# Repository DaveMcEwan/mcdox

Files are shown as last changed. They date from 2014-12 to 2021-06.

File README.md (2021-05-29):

mcdox - Mechanical Computer Keyboard
====================================

Layout is similar to than of the Ergodox project, but in a unibody case.

Subdirectories
--------------

- case - Lasercut design produced by exporting SVGs from KiCAD.
- doc - Documents like datasheets stored for handy reference.
- keycap - STL model generator written in OpenSCAD suitable for FDM printing.
  Generated models are tracked in `keycap/stl` because it takes a while (~10
  minutes) to generate them.
- pcb/ctrl - TODO Breakout PCB for connecting controller to switch grids.
- pcb/hand - Reversible PCB which connects the switches in a grid.
  - 38 buttons distributed over 5 rows, 8 columns.
  - Lengths beside mounting holes (6mm, 15mm, 25mm) are for standoffs to
    achieve a tenting.
  - Connect to control board with 15 core, 1mm pitch FFC-FPC cable.
    <https://www.te.com/usa-en/product-1-84953-5.html>
    <https://www.digikey.com/en/products/detail/te-connectivity-amp-connectors/1-84953-5/2567541>
    <https://uk.farnell.com/amp-te-connectivity/1-84953-5/connector-ffc-fpc-15pos-1rows/dp/3398659>
    <https://uk.farnell.com/multicomp-pro/mp-ffca10150503a/ffc-cord-15p-same-side-50mm-wht/dp/3385337>
    <https://uk.farnell.com/multicomp-pro/mp-ffca10151003a/ffc-cord-15p-same-side-100mm-wht/dp/3385339>
  - Low level lighting with LED on top and/or bottom, depending how the case
    looks.
  - All diodes (1N4148 compatible), LEDs, and resistors are 0603 (imperial).
- release - Stuff that's actually been manufactured.

BOM
---

- Keycaps - The functionally simplest parts which are also the most difficult to
  source.
  18x 1.5u, 56x 1u
- Case - Standard 3mm acrylic from laser cutter.
- PCBs - 1.2mm FR4, 2-layer, 0.15mm width/clearance
  2x mcdoxHand, 1x mcdoxCtrl
- Switches - CherryMX, or compatible like Gateron, Kailh.
  74x
- Diodes - 1 per switch.
  74x
- Microcontroller - Arduino Pro Micro from Sparkfun, or clone.
- FPC connectors
  4x
- FPC cables - Connect hand PCBs to central controller.
- LEDs - 0603 footprint
  2x
- Resistors - For LEDs and switch matrix.
  10x 220R 0603
- Pushbutton - For putting Arduino Pro Micro into programming mode.
  1x

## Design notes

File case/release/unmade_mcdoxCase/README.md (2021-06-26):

Currently unmade - Ready for any future remakes.

Adjustments after session at MVB hackspace on 2020-12-03.
1. Asymmetric hole mistake stops layers being reversible.
  It was off by 5mm but still snapped to grid.
2. Recess for ArduinoProMirco widened by 1mm as it was a very tight press fit.
  This also fixed the very slight asymmetry of the top outline which wasn't
  snapped to grid.
3. Switch hole paths made with straight segments and simplified paths.
  Hope to avoid the odd path planning seen with segments cut in seemingly random
  order.
  It was still the correct cut-points but wasted time flying the lens rather
  than cutting.
4. Pinhole for programming pushbutton through bottom cover.
5. Slightly enlargened keycap cutouts in innerTop to stop caps getting jammed.

DXFs derived from case.svg
--------------------------
```
For each cut layer of case.svg:
  Save a copy as DXF14 using named layer.
  Open DXF in Inkscape.
  Select all, set color to red.
  Reposition for paper size of 400x200mm.
```

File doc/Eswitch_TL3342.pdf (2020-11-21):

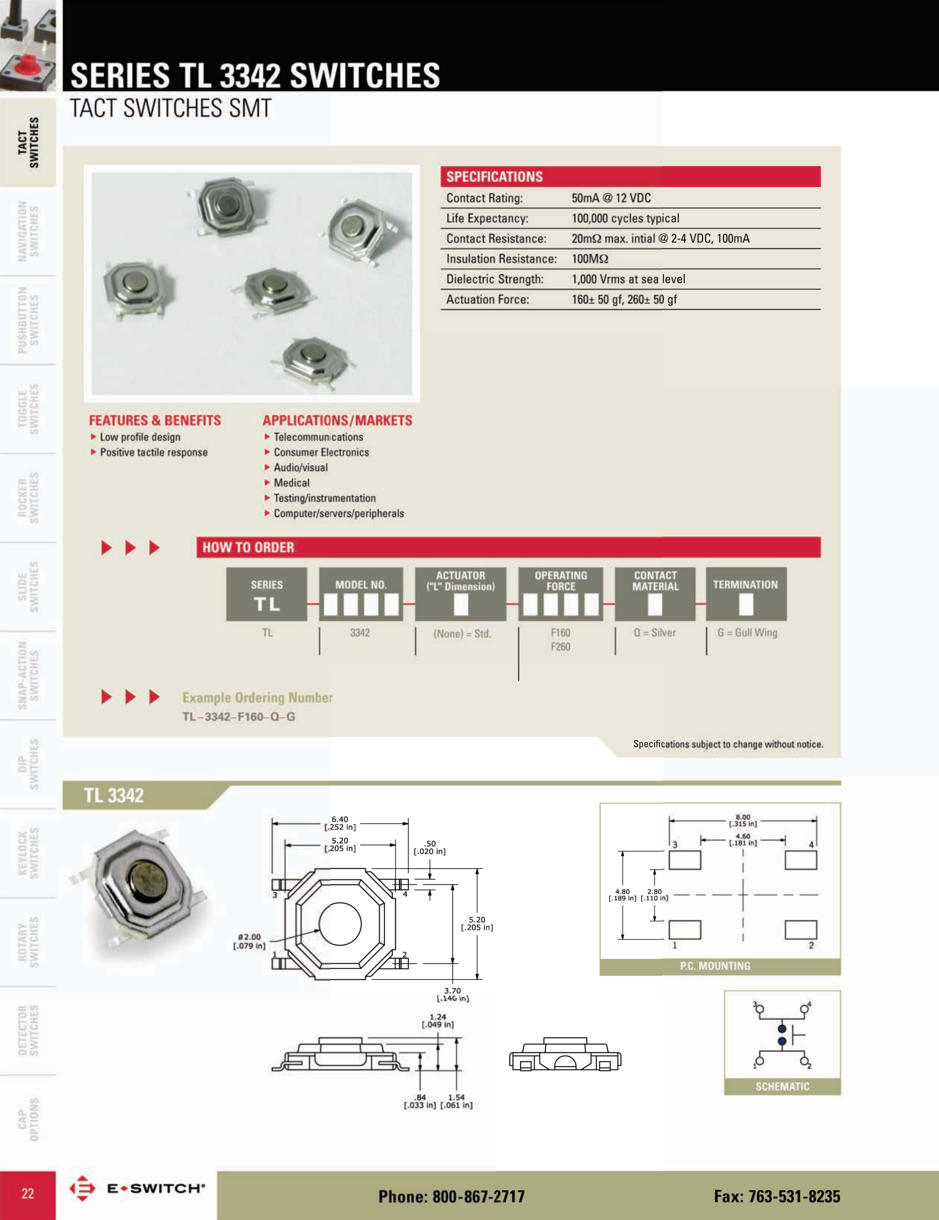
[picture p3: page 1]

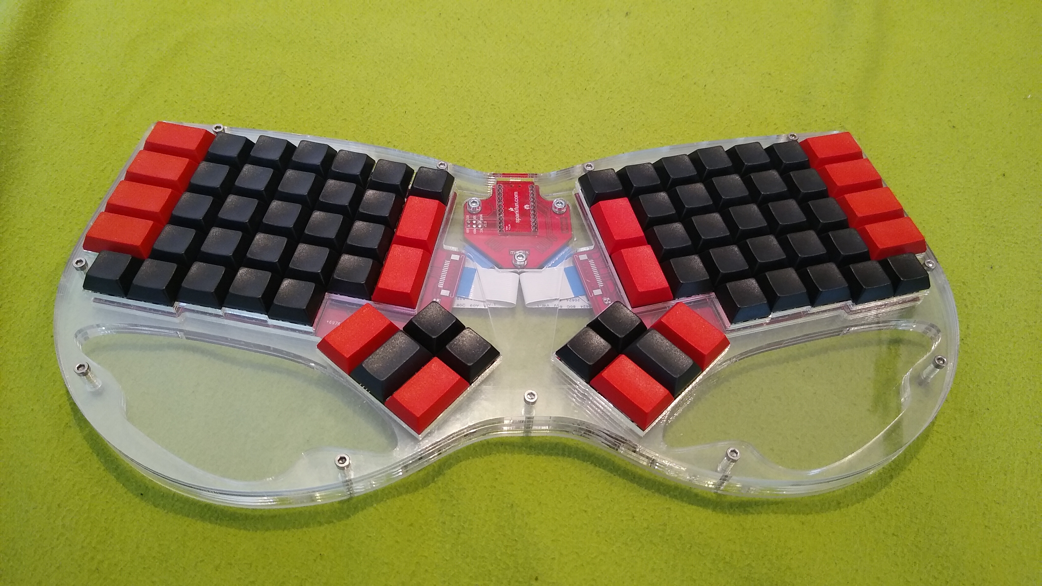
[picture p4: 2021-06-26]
release/mcdoxNov2020/img/top0.jpg

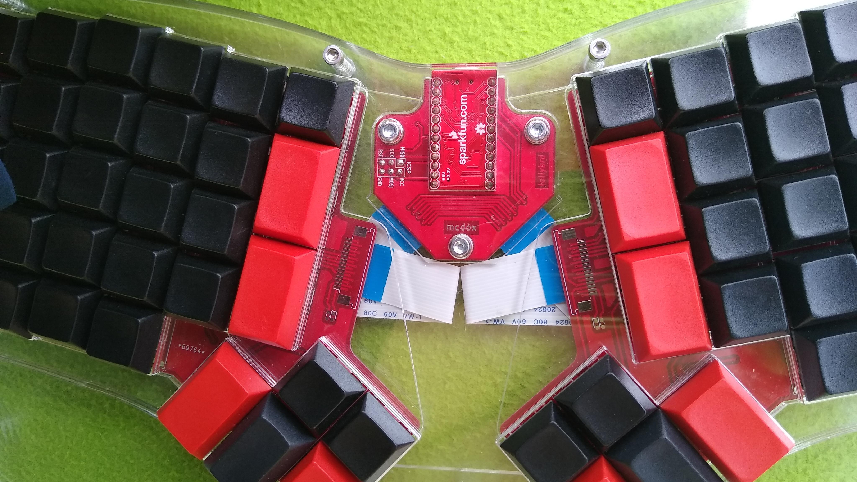
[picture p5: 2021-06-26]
release/mcdoxNov2020/img/ctrl1.jpg

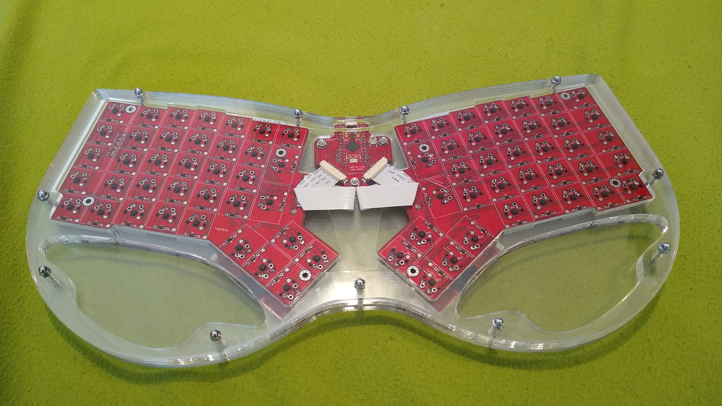
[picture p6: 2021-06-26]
release/mcdoxNov2020/img/bottom0.jpg

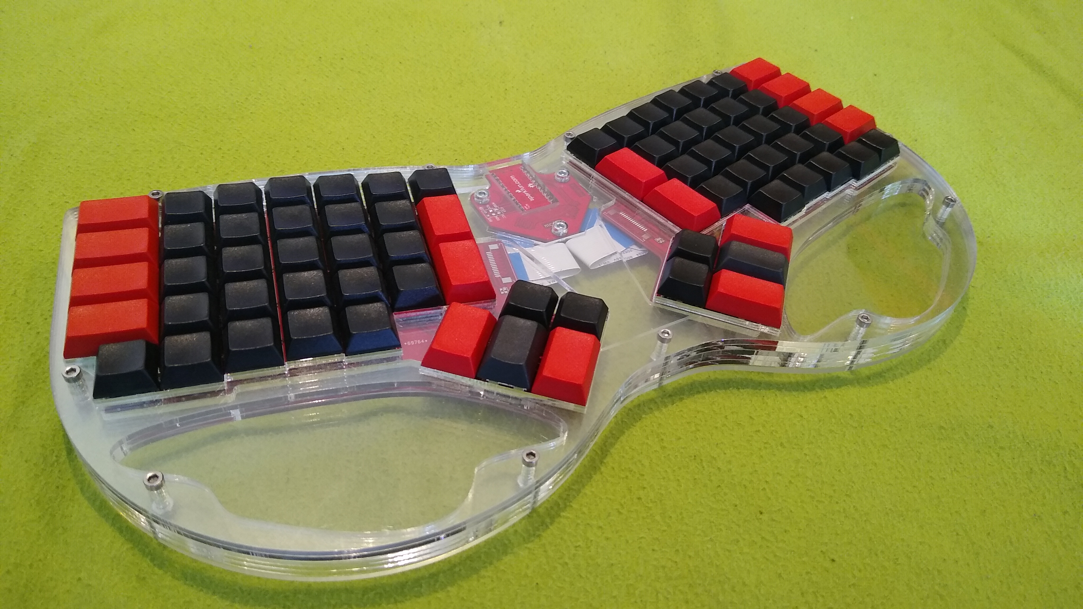
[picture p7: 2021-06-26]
release/mcdoxNov2020/img/top1.jpg

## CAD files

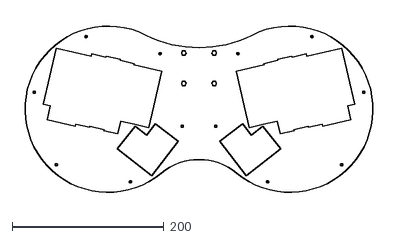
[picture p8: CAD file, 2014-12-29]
case/dxf/mcdox_top0_4mm.dxf
481.3 x 241.5

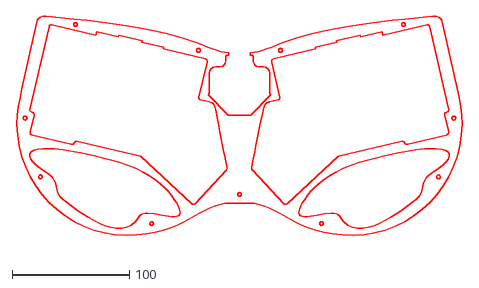
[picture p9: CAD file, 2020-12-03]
case/release/2020-12-03_MVB1.06_mcdoxCase/cut.innerBottom1.dxf
381.5 x 197.5

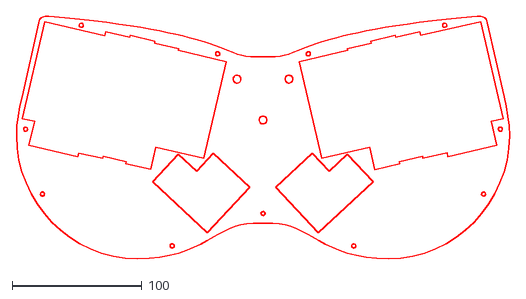
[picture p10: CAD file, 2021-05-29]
case/release/unmade_mcdoxCase/cut.innerTop.dxf
380.0 x 186.8

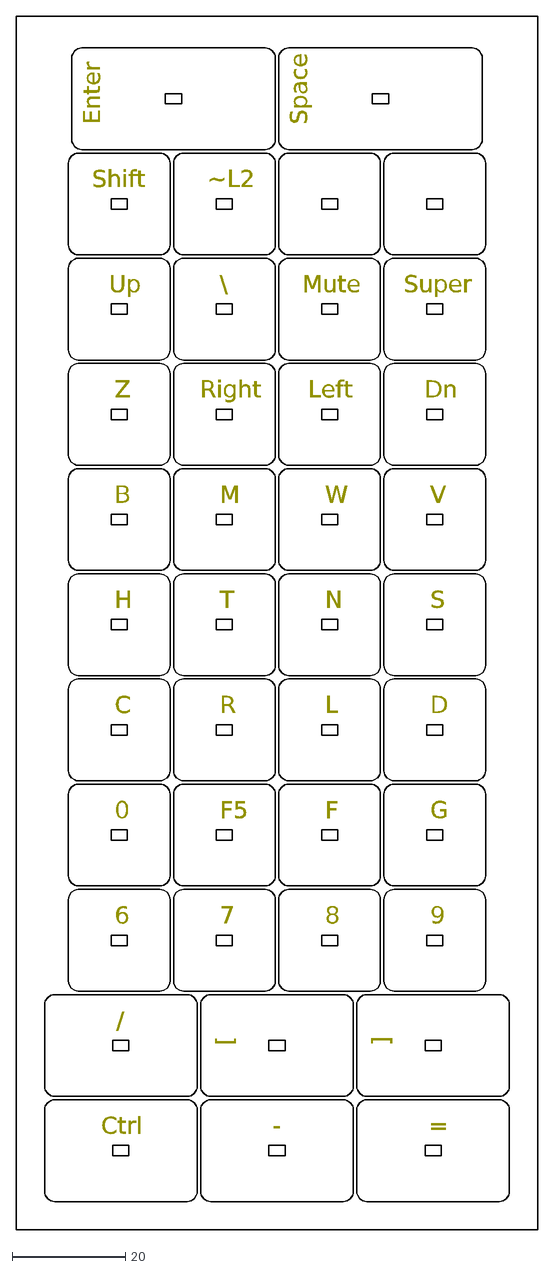
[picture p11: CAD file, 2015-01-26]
keycap/dxf/alps_caps_mcdoxright_3mm.dxf
Ctrl
-
=
/
[
]
6
7
8
9
0
F5
F
G
C
R
L
D
H
T
N
S
B
M
W
V
Z
Right
Left
Dn
Up
\
Mute
Super
Shift
~L2
Enter
Space

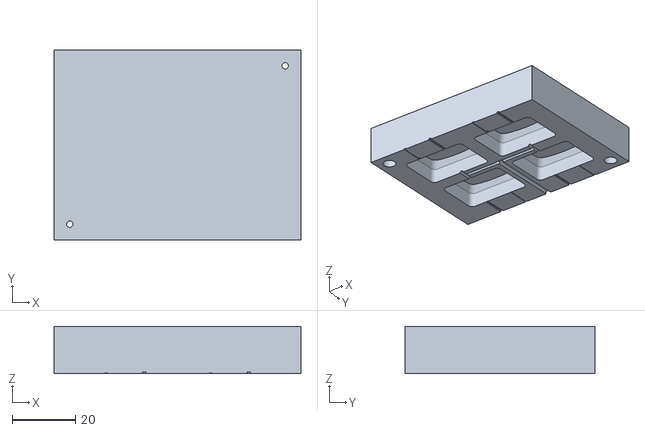
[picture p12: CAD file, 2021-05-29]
keycap/stl/moldUpper,keycap,DSA,CherryMX,1.5u,noBump.stl
78.0 x 60.0 x 15.0

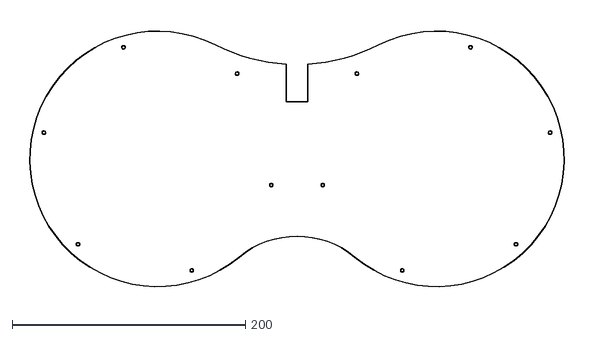
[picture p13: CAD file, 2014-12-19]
case/dxf/mcdox_base0_2mm.dxf
481.3 x 241.5

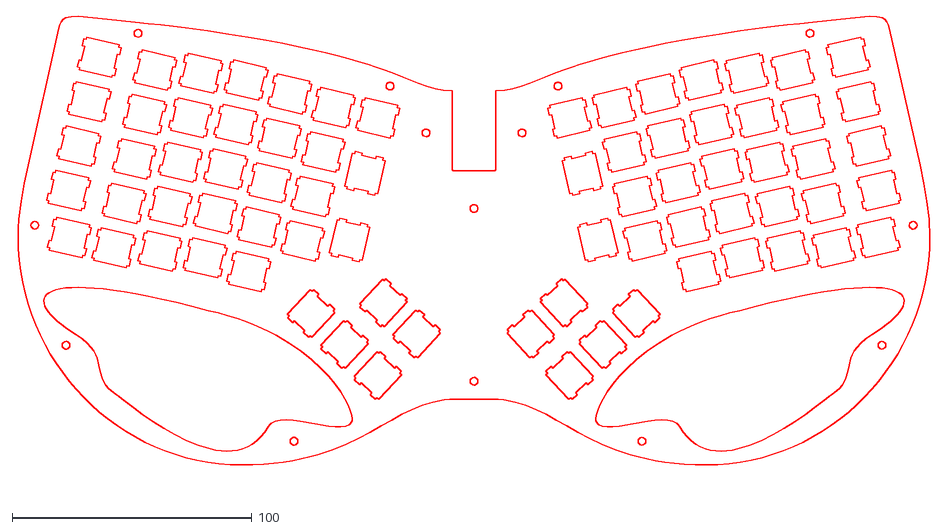
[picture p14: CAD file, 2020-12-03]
case/release/2020-12-03_MVB1.06_mcdoxCase/cut.mount.dxf
381.5 x 197.5

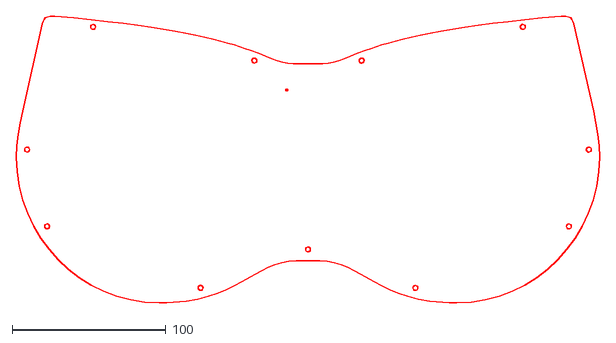
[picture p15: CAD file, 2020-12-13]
case/release/unmade_mcdoxCase/cut.coverBottom.dxf
380.0 x 186.8

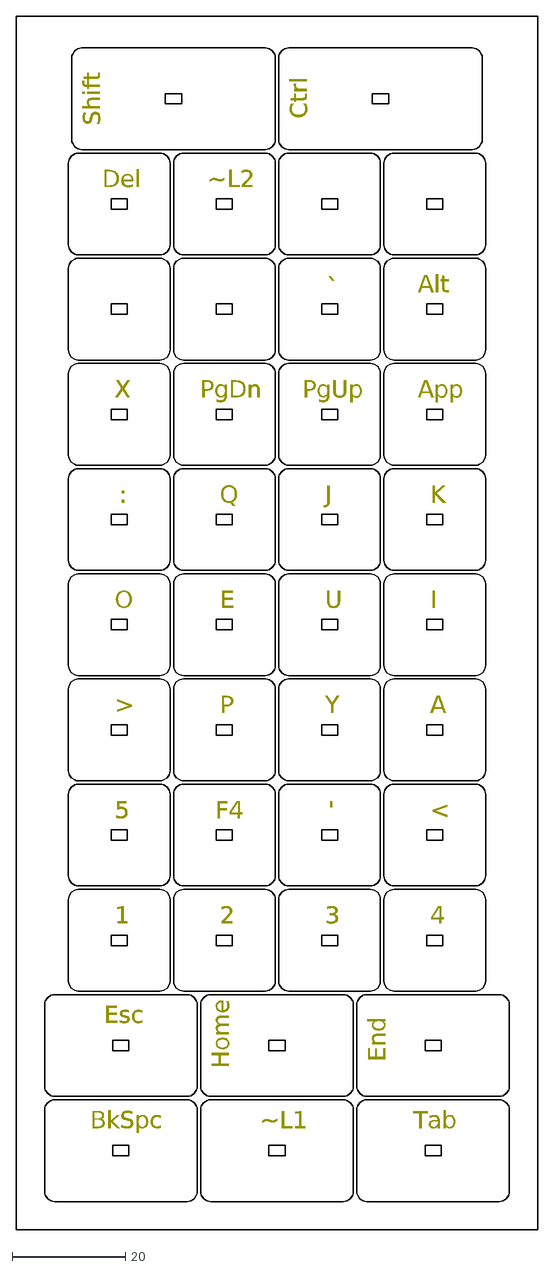
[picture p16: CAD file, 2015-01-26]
keycap/dxf/alps_caps_mcdoxleft_3mm.dxf
BkSpc
~L1
Tab
Esc
Home
End
1
2
3
4
5
F4
'
<
>
P
Y
A
O
E
U
I
:
Q
J
K
X
PgDn
PgUp
App
`
Alt
Del
~L2
Shift
Ctrl

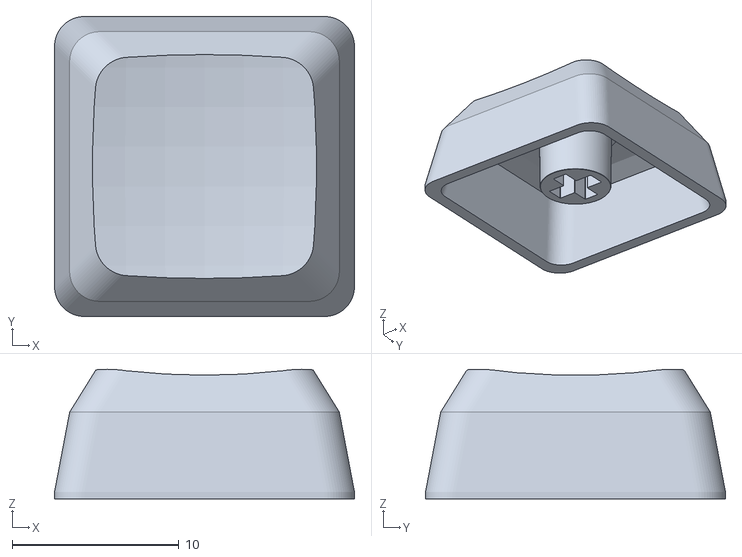
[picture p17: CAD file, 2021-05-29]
keycap/stl/keycap,DSA,CherryMX,1u,noBump.stl
18.0 x 18.0 x 7.77

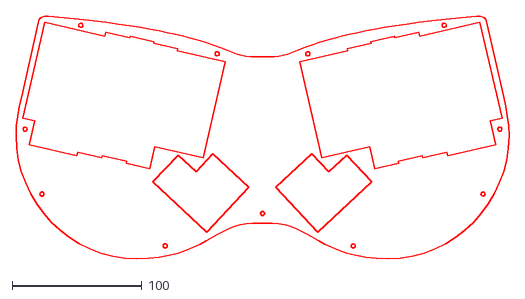
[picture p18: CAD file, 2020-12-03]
case/release/2020-12-03_MVB1.06_mcdoxCase/cut.coverTop.dxf
380.0 x 186.9

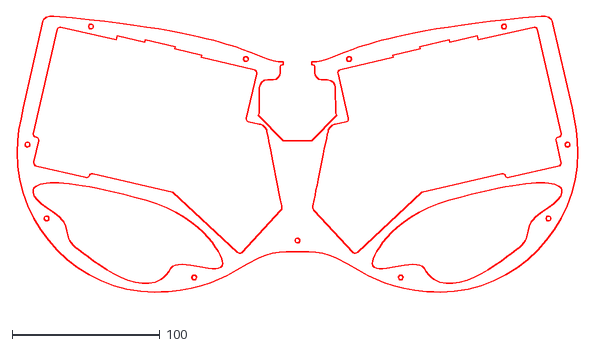
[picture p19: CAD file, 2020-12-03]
case/release/unmade_mcdoxCase/cut.innerBottom1.dxf
381.5 x 197.5

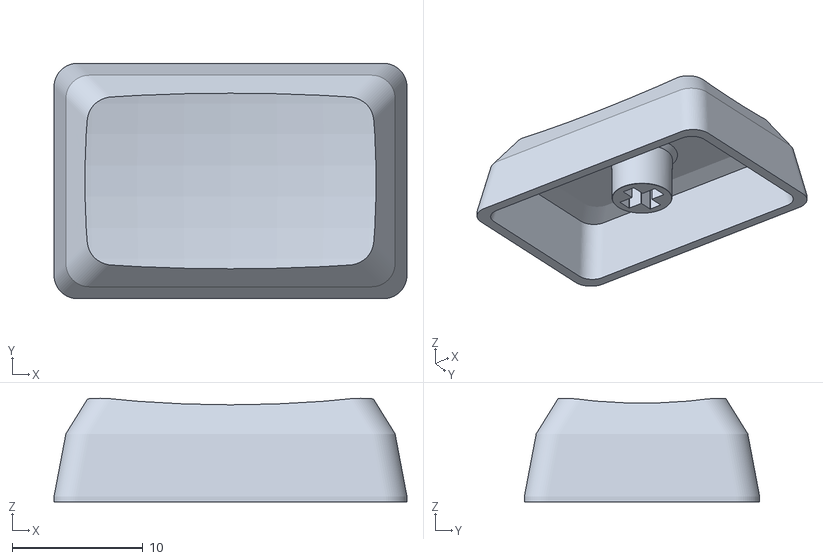
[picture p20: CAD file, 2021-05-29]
keycap/stl/keycap,DSA,CherryMX,1.5u,noBump.stl
27.0 x 18.0 x 7.92

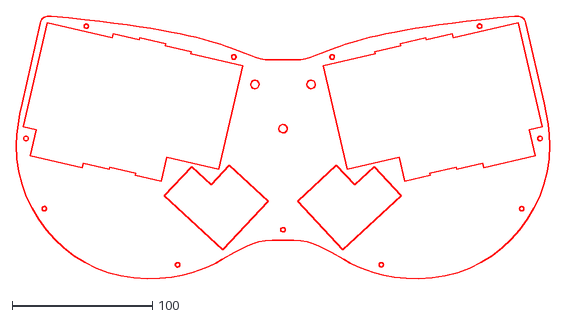
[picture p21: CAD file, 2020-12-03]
case/release/2020-12-03_MVB1.06_mcdoxCase/cut.innerTop.dxf
380.0 x 186.9

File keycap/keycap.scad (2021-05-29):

use <keycapStem.scad>
use <keycapShell.scad>

// Overrideable parameters.
stemNum     = 1;    // Stem shape (CherryMX:1, Matias/ALPS:2)
shellNum    = 1;    // Profile (DSA:1, DCS:2)
uMul        = 1.5;  // Length multiple. Ergodox has (1, 1.5, 2)
doBump      = 0;    // Enable homing bump.

baseUnit = 18.0;

/** Full keycap

mold 0 -> no mold
     1 -> lower negative
     2 -> lower positive, Only for registration trough.
     3 -> upper positive
 */
module keycap (stemNum=1, shellNum=1, uMul=1.0, doBump=0, mold=0) {
  /*
  echo("keycap.scad keycap()");
  echo("\t stemNum=", stemNum);
  echo("\t shellNum=", shellNum);
  echo("\t uMul=", uMul);
  echo("\t doBump=", doBump);
  echo("\t mold=", mold);
  */

  if (1 == mold) {

    difference() {
      color("crimson")
      if (2 == shellNum) innerDCS(u=uMul);
      else               innerDSA(u=uMul);

      color("lightblue")
      if (2 == stemNum) stemMatiasALPS();
      else              stemCherryMX();
    }

  } else if (2 == mold) {

      color("lightgreen")
      if (2 == shellNum) shellDCS(u=uMul, doBump=0);
      else               shellDSA(u=uMul, doBump=0);

  } else if (3 == mold) {

      color("lightgreen")
      if (2 == shellNum) outerDCS(uMul, doBump);
      else               outerDSA(uMul, doBump);

  } else {

    union() {
      color("lightgreen")
      if (2 == shellNum) shellDCS(uMul, doBump);
      else               shellDSA(uMul, doBump);

      color("lightblue")
      if (2 == stemNum) stemMatiasALPS();
      else              stemCherryMX();
    }

  }

}

keycap(stemNum, shellNum, uMul, doBump);

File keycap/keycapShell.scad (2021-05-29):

minDim = 0.001;

baseUnit = 18.0;
draft_deg = 20; // Large taper for easier mold removal, Set for anything.
registration_z = 0.4;

/** Rounded rectangle
*/
module roundedRect (width, height, radius) {
  x = width/2-radius;
  y = height/2-radius;
  hull() {
    translate([-x, -y, 0]) circle(r=radius, $fn=64);
    translate([-x,  y, 0]) circle(r=radius, $fn=64);
    translate([ x, -y, 0]) circle(r=radius, $fn=64);
    translate([ x,  y, 0]) circle(r=radius, $fn=64);
  }
}


module outerDSA (u=1.0, doBump=0) {
  // Top is smaller than base.
  xDiff = 5.3;
  yDiff = 5.3;

  topZ = 7.8;
  dishDepth = 1.2; // Bottom of dish is topZ-dishDepth above origin.
  corner_r = 1.8;

  /** dishVoidDSA Spherical cutout from the top face.
  */
  module dishVoidDSA (u=1.0) {
    r = 38;

    rotate([90, 0, 0])
    translate([0, r, 0])
    scale([u, 1, 1])
    sphere(r=r, $fn=100);
  }

  // Walls are almost straight, but edge at keycap midheight is slightly smaller
  // to make walls slant inwards (draft) for easier mold release.
  wallZ = 5.0;
  d = wallZ * tan(draft_deg); // Reduction length for draft angle.

  union() {
    difference() {
      hull() {
        linear_extrude(minDim)
        roundedRect(baseUnit*u, baseUnit, corner_r);

        translate([0, 0, wallZ])
        linear_extrude(minDim)
        roundedRect(baseUnit*u-d, baseUnit-d, corner_r);

        translate([0, 0, topZ])
        linear_extrude(minDim)
        roundedRect(baseUnit*u-xDiff, baseUnit-yDiff, corner_r);

        // Registration cutout in bottom mold half.
        translate([0, 0, -registration_z/2])
        linear_extrude(registration_z+minDim)
        roundedRect(baseUnit*u, baseUnit, corner_r);
      }

      translate([0, 0, topZ - dishDepth])
      dishVoidDSA(u);
    }

    // Homing bump
    // Usually on the two index finger keys (F,J on qwerty, U,H on dvorak).
    // Sometimes on DSA just a deeper dish is used.
    if (0 != doBump)
      translate([0, 0, topZ - 1.5*dishDepth])
      cylinder(h=0.9, r1=1.9, r2=0.7, center=false, $fn=32);
  }
}

module innerDSA (u=1.0) {
  wallT = 1.0; // Wall thickness
  roofT = 1.1;

  // Top is smaller than base.
  xDiff = 5.3;
  yDiff = 5.3;
  topZ = 6.6 - roofT; // outerDSA.topZ - dishDepth - roofT = 5.5

  corner_r = 1.5;

  // Walls are almost straight, but edge at keycap midheight is slightly smaller
  // to make walls slant inwards (draft) for easier mold release.
  wallZ = 5.0;
  d = wallZ * tan(draft_deg); // Reduction length for draft angle.

  hull() {
    translate([0, 0, -minDim])
    linear_extrude(minDim)
    roundedRect(baseUnit*u - 2*wallT, baseUnit - 2*wallT, corner_r);

    translate([0, 0, wallZ])
    linear_extrude(minDim)
    roundedRect(baseUnit*u-d - 2*wallT, baseUnit-d - 2*wallT, corner_r);

    translate([0, 0, topZ])
    linear_extrude(minDim)
    roundedRect(baseUnit*u-xDiff - 2*wallT, baseUnit-yDiff - 2*wallT, corner_r);

    // Registration cutout in bottom mold half.
    translate([0, 0, -minDim-registration_z])
    linear_extrude(registration_z+minDim)
    roundedRect(baseUnit*u - 2*wallT, baseUnit - 2*wallT, corner_r);
  }
}

module shellDSA (u=1.0, doBump=0) {
  difference() {
    outerDSA(u, doBump);

    innerDSA(u);
  }
}

translate([20, 0, 0])
shellDSA(1.0, 1);

translate([20, 30, 0])
shellDSA(1.5, 1);

translate([50, 0, 0])
color("lightblue")
outerDSA(1.0);

translate([50, 30, 0])
color("lightblue")
outerDSA(1.5);

translate([80, 0, 0])
color("red")
innerDSA(1.0);

translate([80, 30, 0])
color("red")
innerDSA(1.5);


module outerDCS (u=1.0, doBump=0) {
  // Top is smaller than base.
  xDiff = 6;
  yDiff = 4;

  topZ = 8.2;
  dishDepth = 1.0; // Bottom of dish is topZ-dishDepth above origin.
  corner_r = 1.8;

  /** dishVoidDCS Cylindrical cutout from the top face.
  */
  module dishVoidDCS (u=1.0) {
    r = 20;
    tilt_deg = 2.0;

    // Tilt direction is unclear for non-square, so lie cutout flat.
    if (1.0 == u)
      rotate([90-tilt_deg, 0, 90])
      translate([0, r - dishDepth, 0])
      cylinder(h=baseUnit*u+minDim, r=r, center=true, $fn=60);
    else
      rotate([90, 0, 90])
      translate([0, r - dishDepth, 0])
      cylinder(h=baseUnit*u+minDim, r=r, center=true, $fn=60);
  }

  // Walls are almost straight, but edge at keycap midheight is slightly smaller
  // to make walls slant inwards (draft) for easier mold release.
  wallZ = 5.0;
  d = wallZ * tan(draft_deg); // Reduction length for draft angle.

  union() {
    difference() {
      hull() {
        linear_extrude(minDim)
        roundedRect(baseUnit*u, baseUnit, corner_r);

        translate([0, 0, wallZ])
        linear_extrude(minDim)
        roundedRect(baseUnit*u-d, baseUnit-d, corner_r);

        translate([0, 0, topZ])
        linear_extrude(minDim)
        roundedRect(baseUnit*u-xDiff, baseUnit-yDiff, corner_r);
      }

      translate([0, 0, topZ - dishDepth])
      dishVoidDCS(u);
    }

    // Homing bump
    // Usually on the two index finger keys (F,J on qwerty, U,H on dvorak).
    // Sometimes on DSA just a deeper dish is used.
    if (0 != doBump)
      translate([0, 0, topZ - 2.1*dishDepth])
      cylinder(h=0.8, r1=1.9, r2=0.8, center=false, $fn=32);
  }
}

module innerDCS (u=1.0) {
  wallT = 0.8; // Wall thickness
  roofT = 1.3;

  // Top is smaller than base.
  xDiff = 5.3;
  yDiff = 5.3;
  topZ = 7.2 - roofT; // outerDCS.topZ - dishDepth - roofT = 6.4

  corner_r = 1.5;

  // Walls are almost straight, but edge at keycap midheight is slightly smaller
  // to make walls slant inwards (draft) for easier mold release.
  wallZ = 5.0;
  d = wallZ * tan(draft_deg); // Reduction length for draft angle.

  hull() {
    translate([0, 0, -minDim])
    linear_extrude(minDim)
    roundedRect(baseUnit*u - 2*wallT, baseUnit - 2*wallT, corner_r);

    translate([0, 0, wallZ])
    linear_extrude(minDim)
    roundedRect(baseUnit*u-d - 2*wallT, baseUnit-d - 2*wallT, corner_r);

    translate([0, 0, topZ])
    linear_extrude(minDim)
    roundedRect(baseUnit*u-xDiff - 2*wallT, baseUnit-yDiff - 2*wallT, corner_r);
  }
}

module shellDCS (u=1.0, doBump=0) {
  difference() {
    outerDCS(u, doBump);
    innerDCS(u);
  }
}


translate([-20, 0, 0])
shellDCS(1.0, 1);

translate([-20, 30, 0])
shellDCS(1.5, 1);

translate([-50, 0, 0])
color("lightblue")
outerDCS(1.0);

translate([-50, 30, 0])
color("lightblue")
outerDCS(1.5);

translate([-80, 0, 0])
color("red")
innerDCS(1.0);

translate([-80, 30, 0])
color("red")
innerDCS(1.5);

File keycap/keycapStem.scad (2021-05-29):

minDim = 0.001;

innerCorners_r = 0.05;
outerCorners_r = 0.05;
draft_deg = 0.6; // Slight taper for easier mold removal, Set for ABS.
stemRecess = 0.8;

/** Rounded rectangle
*/
module roundedRect (width, height, radius) {
  x = width/2-radius;
  y = height/2-radius;
  hull() {
    translate([-x, -y, 0]) circle(r=radius, $fn=64);
    translate([-x,  y, 0]) circle(r=radius, $fn=64);
    translate([ x, -y, 0]) circle(r=radius, $fn=64);
    translate([ x,  y, 0]) circle(r=radius, $fn=64);
  }
}

/** Inner cross which press-fits onto CherryMX-compatible switch.
*/
module crossVoid () {
  $fn = 64;

  // Enlarge XY dimensions to allow easy but reliable pressfit onto stem.
  pressfitXY = 0.1; // Includes 0.5% shrinkage tolerance.

  // Void above stem for air, mold detritus, dirt, etc.
  pressfitZ = 0.6;

  /** crossVoid cross-section
  Measured on Gateron Brown.

            o----o                       ^
            |    |                       |
            |    |                       |
            |    |                       |
            |    |                       |
   o--------+    +--------o   ^          |
   |                      |   |          |
   |                      |   |          |
   |                      |   |          |
   o--------+    +--------o   v          |
            |    |            crossHd    |
            |    |                       |
            |    |                       |
            |    |                       |
            o----o                       v
                                         crossVl
            <----> crossVd

   <----------------------> crossHl

  */
  crossVd = 1.15 + pressfitXY;
  crossHd = 1.30 + pressfitXY;
  crossVl = 4.00 + pressfitXY;
  crossHl = 4.05 + pressfitXY;
  crossZ = 3.50 + pressfitZ + minDim; // minDim for later difference().

  /** Top-Rounded Cuboid
  Where draft angle is non-zero this is technically a trapezoid.
  Base is centered on origin with original dimensions with 2D rounded corners.
  Top is centered on +Z with drafted dimensions (slightly smaller) and 3D rounded
  corners.
  */
  module toproundedCube (width, height, depth, radius, topDelta) {
    xTop = width/2 - radius - topDelta;
    yTop = height/2 - radius - topDelta;
    zTop = depth - radius;

    hull() {
      linear_extrude(minDim) roundedRect(width, height, radius);

      translate([-xTop, -yTop, zTop]) sphere(r=radius);
      translate([-xTop,  yTop, zTop]) sphere(r=radius);
      translate([ xTop, -yTop, zTop]) sphere(r=radius);
      translate([ xTop,  yTop, zTop]) sphere(r=radius);
    }
  }

  /** Four Inner Corners with draft and inner and outer radius.
  Rotational extrusions take more code but render much faster than minkowski.
  */
  module innerCorners (offsetX, offsetY, inner_r, outer_r, topDelta, depth) {

    module innerCorner (outer_r, inner_r, topDelta, depth) {

      rotate_extrude(angle=90)
      hull() {
        translate([outer_r + topDelta + inner_r, depth - outer_r, 0])
        union() {
          circle(r=outer_r);

          translate([outer_r, 0])
          square([outer_r*2, outer_r*2], center=true);
        }

        translate([inner_r, 0, 0])
        square([outer_r*2, minDim], center=false);
      }
    }

    x = offsetX/2 + inner_r;
    y = offsetY/2 + inner_r;

    translate([-x, -y, 0])
    innerCorner(outer_r, inner_r, topDelta, depth);

    translate([x, -y, 0])
    rotate([0, 0, 90])
    innerCorner(outer_r, inner_r, topDelta, depth);

    translate([x, y, 0])
    rotate([0, 0, 180])
    innerCorner(outer_r, inner_r, topDelta, depth);

    translate([-x, y, 0])
    rotate([0, 0, 270])
    innerCorner(outer_r, inner_r, topDelta, depth);
  }

  d = crossZ * tan(draft_deg); // Reduction length for draft angle.

  translate([0, 0, -minDim/2]) // minDim for later difference().
  union() {
    toproundedCube(crossVd, crossVl, crossZ, outerCorners_r, d);
    toproundedCube(crossHl, crossHd, crossZ, outerCorners_r, d);
    innerCorners(crossVd, crossHd, outerCorners_r, innerCorners_r, d, crossZ);
  }
}

/** Round pillar with support collar at top.
*/
module solidPillar () {
  diameter = 5.6;

  // Measurements from existing piece.
  height = 5.0 - stemRecess;

  radius = diameter / 2;
  d = height * tan(draft_deg); // Expansion at top for draft angle.

  union() {
    hull() {
      translate([0, 0, height-minDim/2])
      cylinder(h=minDim, r=radius+d, center=true, $fn=256);

      translate([0, 0, outerCorners_r])
      rotate_extrude($fn=256)
      translate([radius - outerCorners_r, outerCorners_r/2, 0])
      circle(r=outerCorners_r, $fn=32);
    }

    // Support structure to reduce stress on joining corners.
    // 45deg collar intended to be mostly removed in final keycap.
    collarZ = 1.0;
    translate([0, 0, height-minDim])
    cylinder(h=collarZ, r1=radius+d, r2=radius+collarZ, center=false, $fn=256);
  }
}

/** Circular Stem for CherryMX, Pre-positioned with Z-recess.
*/
module stemCherryMX () {
  translate([0, 0, stemRecess])
  difference() {
    solidPillar();
    crossVoid();
  }
}
stemCherryMX();

translate([20, 0, 0])
color("red")
crossVoid();

translate([10, 0, 0])
color("blue")
solidPillar();

/** Cuboid Stem for Matias/ALPS, Pre-positioned with Z-recess.
*/
module stemMatiasALPS () {

  // Enlarge XY dimensions to allow easy but reliable pressfit onto stem.
  pressfitXY = 0.05; // Includes 0.5% shrinkage tolerance.

  // Void above stem for air, mold detritus, dirt, etc.
  pressfitZ = 0.6;

  /** stem cross-section
  Measured on Matias ALPS tactile.

   o----------------------o   ^
   |                      |   |
   |                      |   |
   |                      |   |
   o----------------------o   v
                              holeVl

   <----------------------> holeHl

  */
  holeVl = 2.15 + pressfitXY;
  holeHl = 4.35 + pressfitXY;
  holeZ = 5.00 + pressfitZ;


  height = holeZ - stemRecess;
  d = height * tan(draft_deg); // Expansion at top for draft angle.

  xBot = holeHl/2 - outerCorners_r;
  yBot = holeVl/2 - outerCorners_r;
  zBot = outerCorners_r;
  xTop = holeHl+d;
  yTop = holeVl+d;
  zTop = height;


  translate([0, 0, stemRecess])
  union() {
    hull() {
      translate([0, 0, zTop])
      linear_extrude(minDim)
      roundedRect(xTop, yTop, outerCorners_r);

      translate([-xBot, -yBot, zBot]) sphere(r=outerCorners_r, $fn=64);
      translate([-xBot,  yBot, zBot]) sphere(r=outerCorners_r, $fn=64);
      translate([ xBot, -yBot, zBot]) sphere(r=outerCorners_r, $fn=64);
      translate([ xBot,  yBot, zBot]) sphere(r=outerCorners_r, $fn=64);
    }

    // Support structure to reduce stress on joining corners.
    // 45deg collar intended to be mostly removed in final keycap.
    collarZ = 1.0;
    collarR1 = 0.5 * sqrt(pow(xTop, 2) + pow(yTop, 2));
    collarR2 = 0.5 * holeHl + collarZ;
    translate([0, 0, height-minDim])
    cylinder(h=collarZ, r1=collarR1, r2=collarR2, center=true, $fn=256);
  }
}
translate([0, 10, 0])
stemMatiasALPS();

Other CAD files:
case/release/unmade_mcdoxCase/cut.coverTop.dxf
keycap/stl/moldUpper,keycap,DSA,CherryMX,1u,noBump.stl
case/release/2020-12-03_MVB1.06_mcdoxCase/cut.coverBottom.dxf
case/release/unmade_mcdoxCase/cut.mount.dxf
keycap/mold.scad
case/release/2020-12-03_MVB1.06_mcdoxCase/cut.innerBottom0.dxf
case/release/unmade_mcdoxCase/cut.innerBottom0.dxf
keycap/moldIsogrid.scad
keycap/stl/keycap,DSA,CherryMX,1u,yesBump.stl
keycap/stl/moldUpper,keycap,DSA,CherryMX,1u,yesBump.stl

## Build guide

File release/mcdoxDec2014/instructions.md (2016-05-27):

Instructions for mcdox v1.0
===========================

These are the basic steps to complete in order.
Use the photographs for clarification.

1. Send SVG files to acrylic laser cutters.
2. Send Gerber files to PCB manufacturer (lollybrd + mcdoxhand).
3. Solder/assemble lollybrd PCB.
4. Solder diodes onto mcdoxhand PCBs.
5. Insert switches into mnt layer of case.
6. Lay mcdoxhand PCBs over switches and solder in place.
7. Mount lollybrd PCB onto mnt layer or case with socket-head M3 bolts.
8. Arrange other case layers in order, lining up fixing holes.
9. Insert button-head M3 bolts in fixing holes and finger tighten dome nuts.
10. Put keycaps onto switches.
11. Compile TMK firmware (or use `mcdox_pjrc.hex`). flash using Teensy Loader.

Et voila!
Just in case that isn't enough there are some more details below.

I feel happy releasing this as v1.0 because I have tested it daily for over a
year and am satisfied that the ergonomics work well and it feels like a solid
build.
The build and assembly process was very easy and I'm confident most people with
very basic C and soldering skills could replicate my work.

Designed, built, tested by Dave McEwan 2014-2016.

Parts List
----------

  - Bolts M3-32mm button-head               x12
  - Bolts M3-10mm socket-head               x4
  - Dome Nuts M3                            x12
  - Flat Nuts M3                            x4
  - Washers M3                              x32
  - Diodes 1N4148                           x76
  - PJRC Teensy-2.0                         x1
  - PCB (mcdoxhand)                         x2
  - PCB (lollybrd)                          x1
  - 13-core, 1.27mm pitch IDC Ribbon Cable  x2
  - Switches CherryMX OR Matias ALPS        x76
  - Keycap 1.0u                             x60
  - Keycap 1.5u                             x12
  - Keycap 2.0u                             x4
  - Case (laser cut)                        x1

Laser Cut Acrylic Case With SVG Files
-------------------------------------

  - `mcdox_5mm.svg` - Clear
  - `mcdox_cherrymx_3mm.svg` OR `mcdox_alps_3mm.svg` - Black

Different laser cutting shops prefer different file formats though EPS seems to
be the best supported.
You can tailor the SVG files in Inkscape to whatever specifications your chosen
shop requires.
Typically you want to merge all the files for the same thickness material into
one SVG, convert everything to paths, and "Save As' in Encapsulated PostScript
format.

For each case expect to pay around 20 GPB in materials if using just 3mm and
5mm acrylic.
For each CherryMX case expect to pay for around 20 minutes in cutting time.
For each ALPS case expect to pay for around 30 minutes in cutting time.

Case thickness is sum(3, 5, 5, 3, 5, 3) = 24mm.
M3 acorn nuts which act as feet lift it another 5mm to the bottom.
Keycaps protrude about 5mm from the top.
Total height off the desk is about 34mm.

PCB Manufacture With Gerber Archives
------------------------------------

  - `lollybrd_gerber.zip` - The controller PCB.
  - `mcdoxhand_gerber.zip` - The hand PCB, reversible.

Size of the controller board (lollybrd) is 50x50mm which is very cheap from
SeeedStudio and other low cost, low volume PCB manufacturers.
You need one copy of the lollybrd PCB and 2 copies of the mcdoxhand PCB.
For 2.5 keyboards worth (5 * mcdoxhand + 10 * lollybrd), expect to pay around
60 GBP, this was the minimum order when I tried.

The recommended PCB specs required are basic.

  - 2 layer - Both designs only use 2.
  - 1.6mm FR4 - Usually the cheapest option, doesn't really matter.
  - 15 mil (or less) routes/clearance

Instead of finding 13-core ribbon cable I just sliced a standard 26-core IDE
cable in half.

Firmware With HEX file
----------------------

TMK from my branch with the PJRC loader.
Make any edits to your favourite keymap (I like dvorak) in
`tmk_keyboard/keyboard/mcdox/keymap_dvorak.h` then compile.

    cd tmk_keyboard/keyboard/mcdox
    make dvorak -f Makefile.pjrc

Then drag/drop `mcdox_pjrc.hex` into the Teensy Loader and click program.

Notes And Future Improvements
-----------------------------

I used black M3 washers at both ends of the fixing bolts to allow the dome nuts
to be better positioned on the end of the bolt.
This is really unnecessary and after about 7 months the colour on the top of the
washers started to rub off looking a bit crap.
Forget the washers. If the bolt is too long just file/grind it down.

The 4 thumb keys (2.0u) are sometimes a bit wobbly.
I've seen others using stabilisers but these seem hard to come by.
I could just use 1.5u instead which would mean less wobbly switches and less
different parts.
This would alter the layout slightly but might make it easier to reach opposite
corners with one hand.

The col/row arrangement should be swapped around to save a GPIO pin.
The arrangement of 6 (horizontal) columns and 2x 7 (vertical) rows requires 20
GPIO where columns are driven and rows are read.
This is the same as the ErgoDox where this detail did not matter since there
was no shared columns between sides.
By arranging as 7 (vertical) columns and 2x 6 (horizontal) rows only requires 19
GPIO, and looks more intuitive.
Columns are still driven, rows are still read.

Splaying and soldering the ribbon cable is not production friendly and feels
like the ugliest part of the design.
Using low profile FPC ZIF connectors and cable would be much neater.
The Raspberry Pi camera module uses a 15-pin FPC so these are readily available
to potential keyboard hackers, as well as production facilities.

PimpMyKeyboard who supply keycaps are based in USA and charge very high
shipping, plus HMRC charge 20% VAT, plus Post Office charge 8GBP handling fee.
That all ends up at about 50GBP per board, even in 10+ quantities.
Devlin Electronics in UK are much cheaper, coming in at about 15GBP per board
before shipping of 12GBP.

Wireless would be nice, especially with my TV.
BlueTooth4 Low Energy (BLE) features USB pass through.
Wired and charging while plugged in, bluetooth when unplugged.
Should have a toggle switch on top.

Acrylic case becomes smudged quite easily and is rather heavy.
Replace 5mm layers with 4mm acrylic, and 3mm layers with 2mm aluminium to reduce
thickness by a third.
This also opens up the possibility of having a tented profile.

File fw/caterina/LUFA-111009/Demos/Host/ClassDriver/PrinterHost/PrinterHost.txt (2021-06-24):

/** \file
 *
 *  This file contains special DoxyGen information for the generation of the main page and other special
 *  documentation pages. It is not a project source file.
 */

/** \mainpage Printer Host Demo
 *
 *  \section Sec_Compat Demo Compatibility:
 *
 *  The following list indicates what microcontrollers are compatible with this demo.
 *
 *  - Series 7 USB AVRs (AT90USBxxx7)
 *
 *  \section Sec_Info USB Information:
 *
 *  The following table gives a rundown of the USB utilization of this demo.
 *
 *  <table>
 *   <tr>
 *    <td><b>USB Mode:</b></td>
 *    <td>Host</td>
 *   </tr>
 *   <tr>
 *    <td><b>USB Class:</b></td>
 *    <td>Printer Device</td>
 *   </tr>
 *   <tr>
 *    <td><b>USB Subclass:</b></td>
 *    <td>Bidirectional Protocol</td>
 *   </tr>
 *   <tr>
 *    <td><b>Relevant Standards:</b></td>
 *    <td>USBIF Printer Class Specification \n
 *        PCL Language Specification</td>
 *   </tr>
 *   <tr>
 *    <td><b>Usable Speeds:</b></td>
 *    <td>Low Speed Mode \n
 *        Full Speed Mode</td>
 *   </tr>
 *  </table>
 *
 *  \section Sec_Description Project Description:
 *
 *  Printer host demonstration application. This gives a simple reference
 *  application for implementing a USB Printer host, for USB printers using
 *  the bidirectional data encapsulation protocol and PCL language.
 *
 *  Upon connection of a compatible printer, the printer's device ID is sent
 *  to the AVR's serial port, and a simple test page is printed using the PCL
 *  printer language.
 *
 *  \section Sec_Options Project Options
 *
 *  The following defines can be found in this demo, which can control the demo behaviour when defined, or changed in value.
 *
 *  <table>
 *   <tr>
 *    <td>
 *     None
 *    </td>
 *   </tr>
 *  </table>
 */

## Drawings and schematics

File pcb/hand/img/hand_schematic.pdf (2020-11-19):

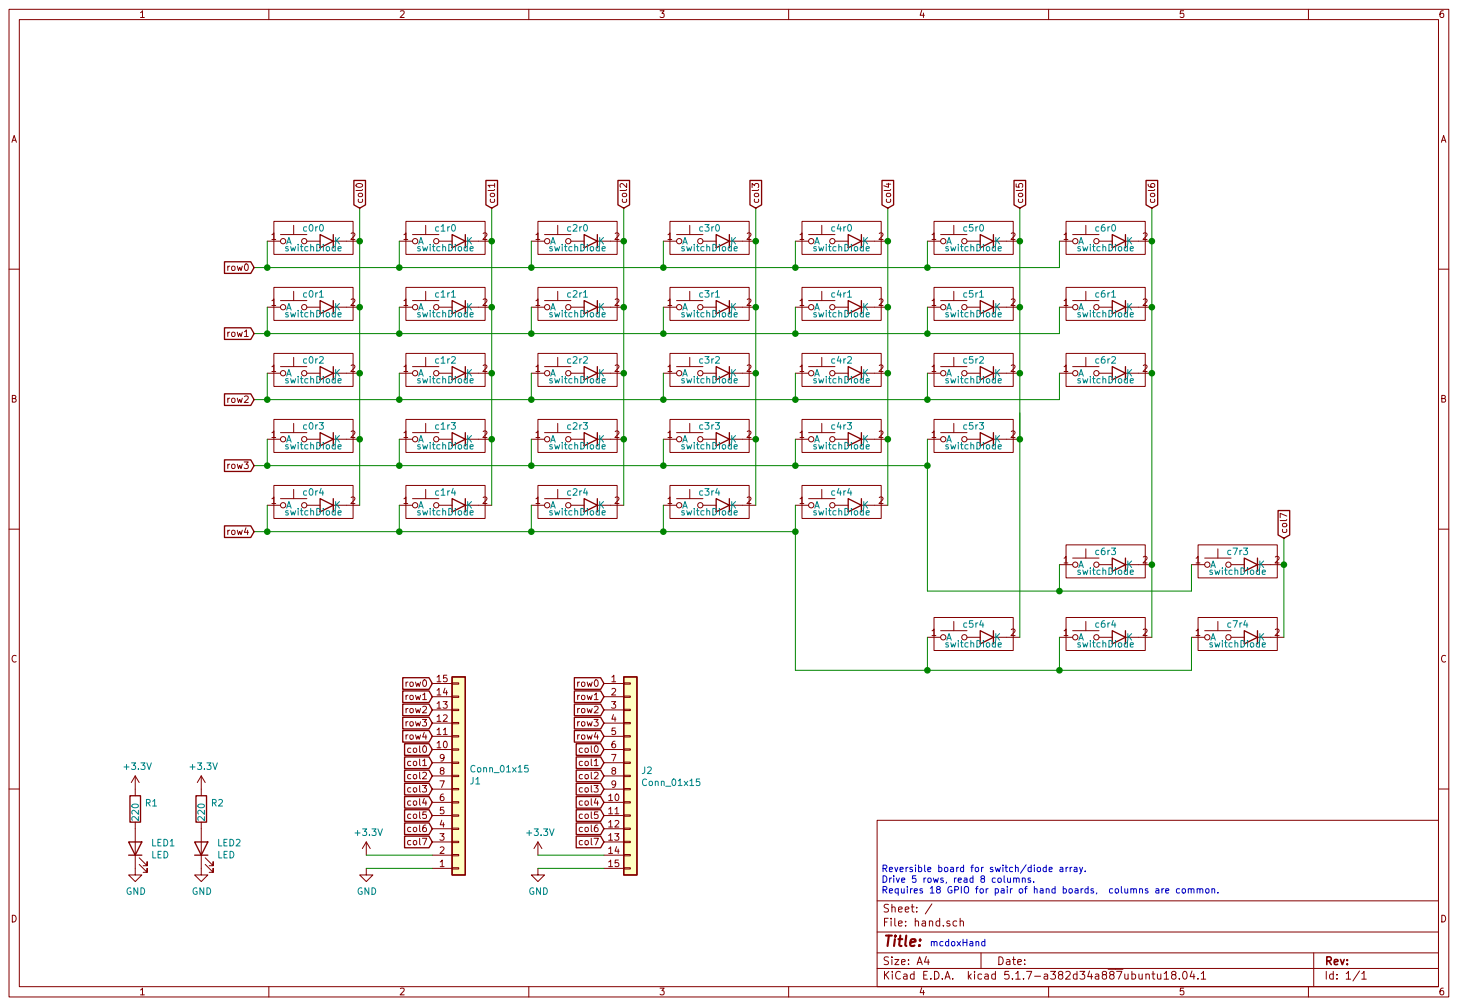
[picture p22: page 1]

Reversible board for switch/diode array. Drive 5 rows, read 8 columns. Requires 18 GPIO for pair of hand boards, columns are common. mcdoxHand

Id: 1/1 Title: File: hand.sch Sheet: / GND

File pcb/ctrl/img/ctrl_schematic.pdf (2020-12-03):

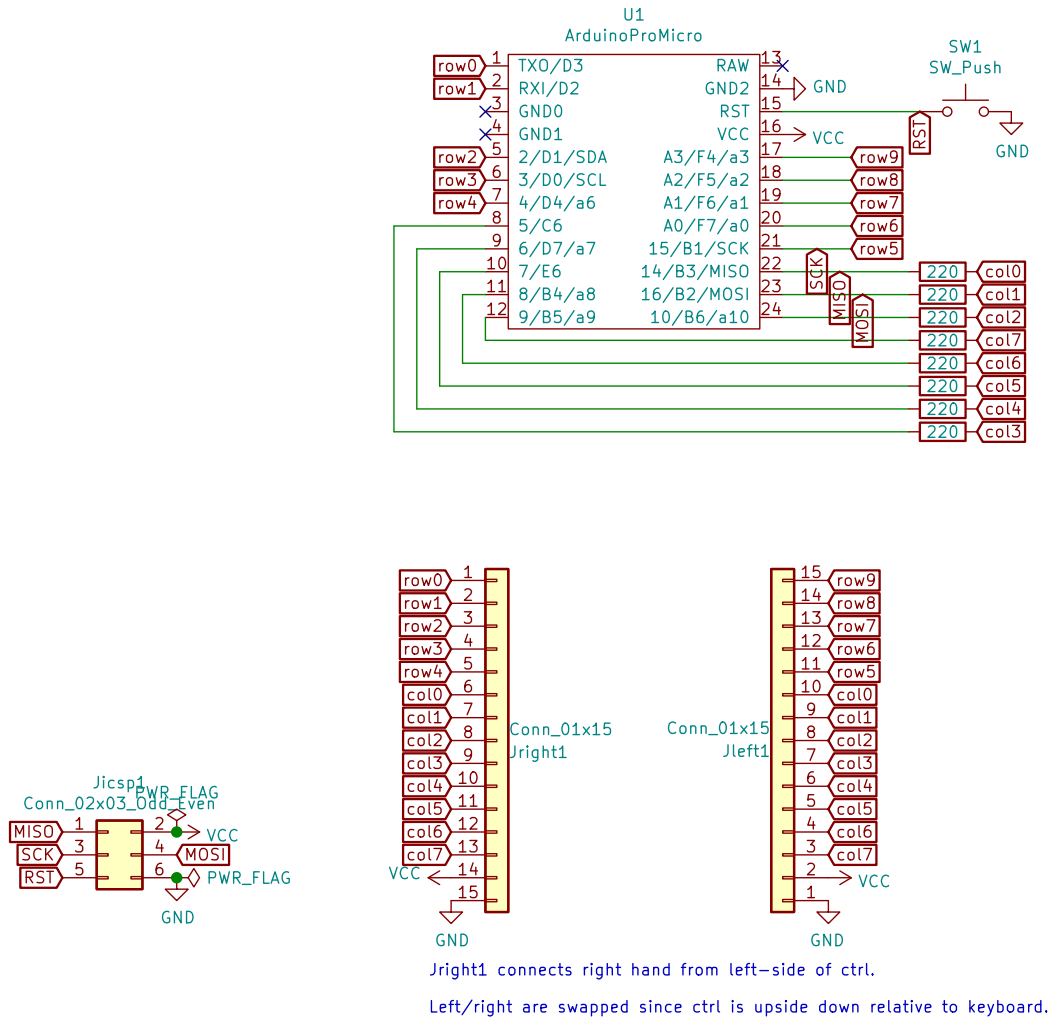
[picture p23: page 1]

col7 Drive rows, read common columns. Jright1 connects right hand from left-side of ctrl.
PWR_FLAG

Left/right are swapped since ctrl is upside down relative to keyboard.

Id: 1/1 Title: File: ctrl.sch Sheet: /

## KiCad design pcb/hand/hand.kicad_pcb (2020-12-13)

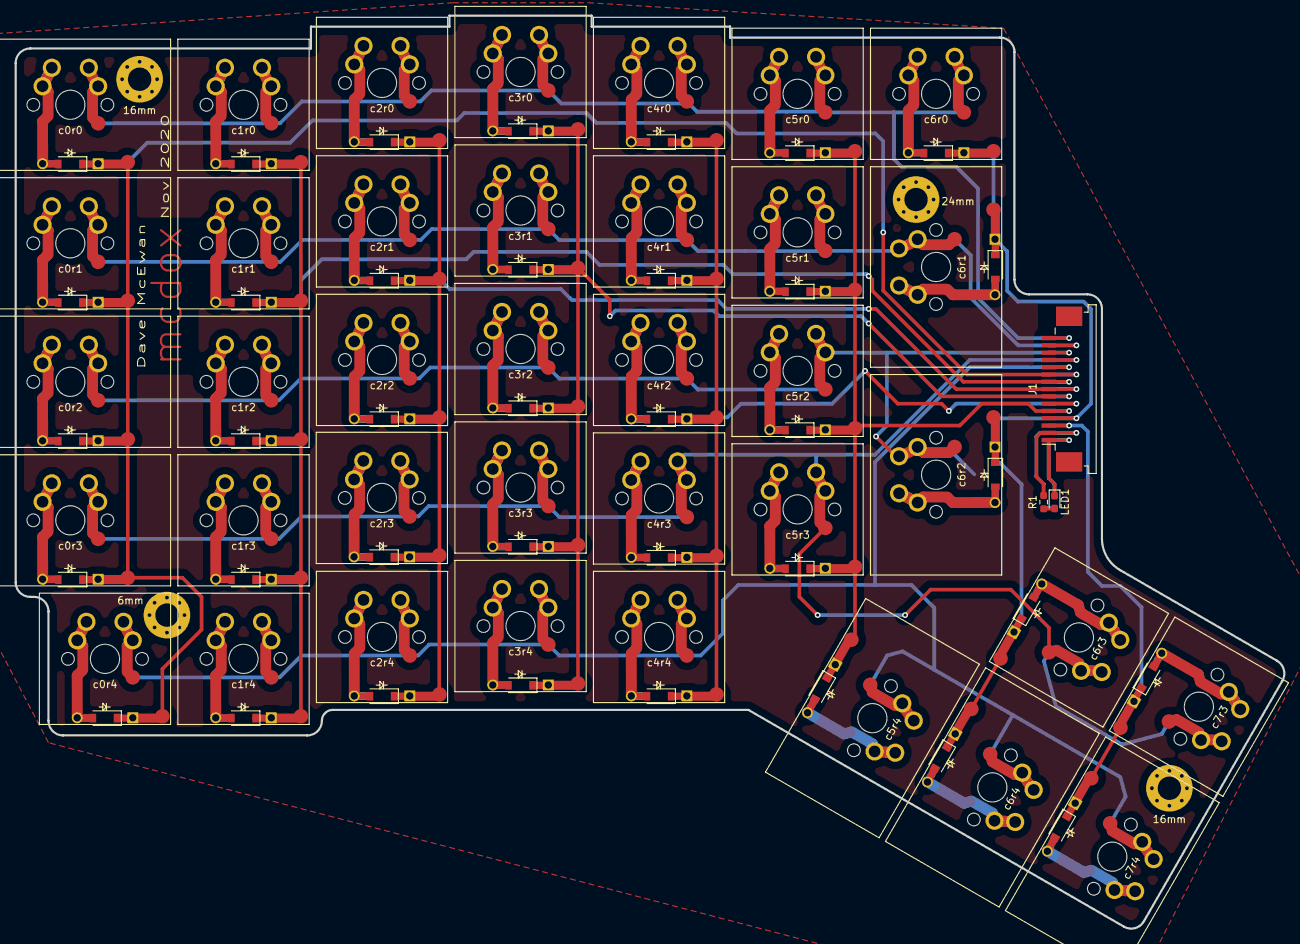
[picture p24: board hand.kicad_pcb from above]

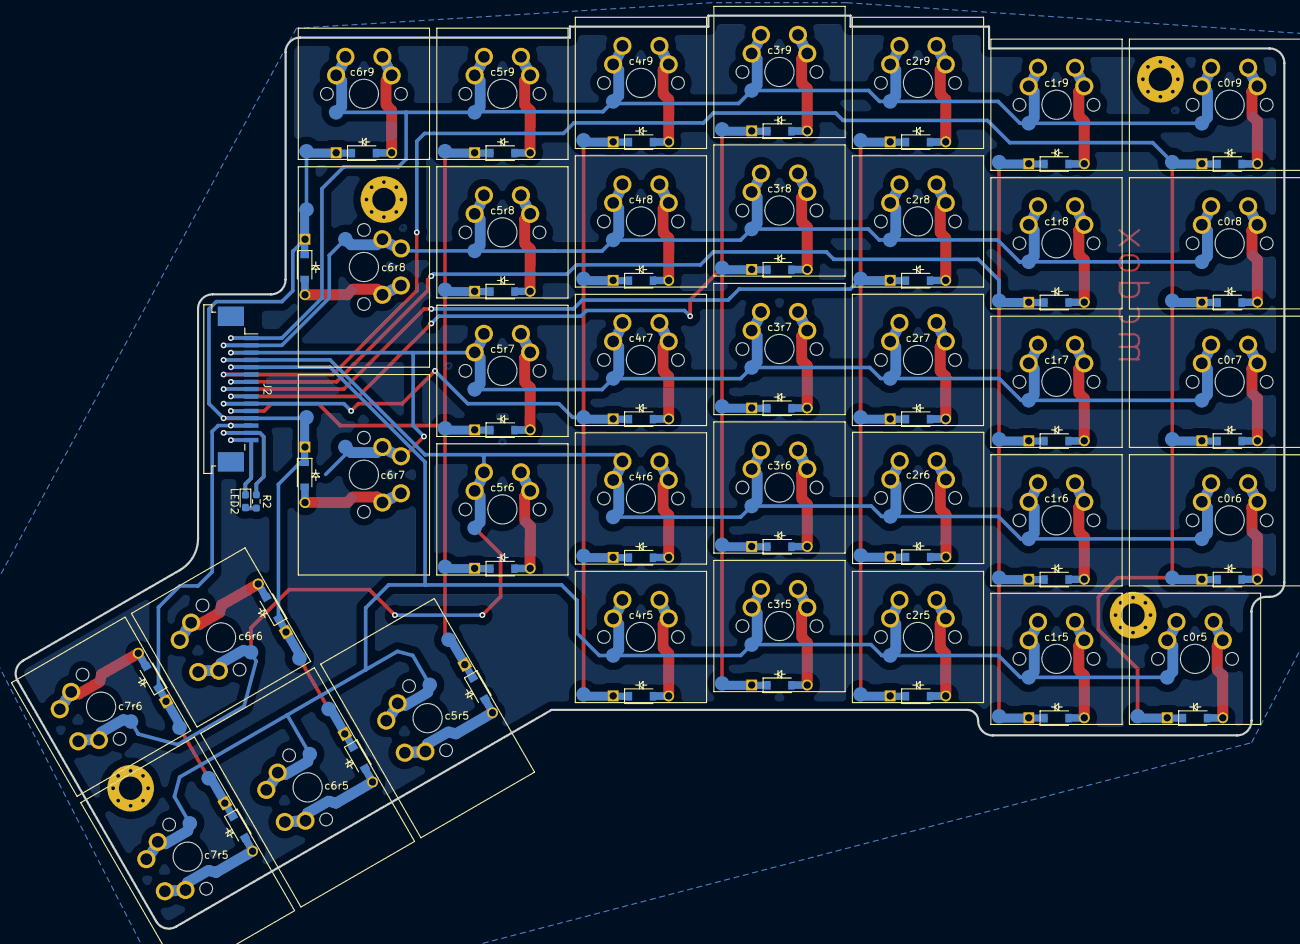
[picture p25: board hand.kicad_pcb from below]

Board: 2 copper layers, 174.0 x 125.2 mm, 47 parts (6 on the bottom side), 17 nets.

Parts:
6mm, 16mm, 16mm#2, 24mm: MountingHole_3.2mm_M3_Pad_Via
J1, J2: Conn_01x15; TE_1-84953-5_1x15-1MP_P1.0mm_Horizontal
LED1, LED2: LED; D_0603_1608Metric_Pad1.05x0.95mm_HandSolder
R1, R2: 100; R_0603_1608Metric_Pad0.98x0.95mm_HandSolder
c0r0, c0r1, c0r2, c0r3, c5r4, c6r1, c6r2, c6r4, c7r4: switchDiode; reversibleMX_15u
c0r4, c1r0, c1r1, c1r2, c1r3, c1r4, c2r0, c2r1, c2r2, c2r3, c2r4, c3r0, c3r1, c3r2, c3r3, c3r4, c4r0, c4r1, c4r2, c4r3, c4r4, c5r0, c5r1, c5r2, c5r3, c6r0, c6r3, c7r3: switchDiode; reversibleMX_10u

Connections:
+3V3: J1.2, J2.14, R1.1, R2.1
GND: J1.1, J2.15, LED1.1, LED2.1
unnamed: LED1.2, R1.2
unnamed: LED2.2, R2.2
col0: J1.10, J2.6, c0r0.2, c0r1.2, c0r2.2, c0r3.2, c0r4.2
col1: J1.9, J2.7, c1r0.2, c1r1.2, c1r2.2, c1r3.2, c1r4.2
col2: J1.8, J2.8, c2r0.2, c2r1.2, c2r2.2, c2r3.2, c2r4.2
col3: J1.7, J2.9, c3r0.2, c3r1.2, c3r2.2, c3r3.2, c3r4.2
col4: J1.6, J2.10, c4r0.2, c4r1.2, c4r2.2, c4r3.2, c4r4.2
col5: J1.5, J2.11, c5r0.2, c5r1.2, c5r2.2, c5r3.2, c5r4.2
col6: J1.4, J2.12, c6r0.2, c6r1.2, c6r2.2, c6r3.2, c6r4.2
col7: J1.3, J2.13, c7r3.2, c7r4.2
row0: J1.15, J2.1, c0r0.1, c1r0.1, c2r0.1, c3r0.1, c4r0.1, c5r0.1, c6r0.1
row1: J1.14, J2.2, c0r1.1, c1r1.1, c2r1.1, c3r1.1, c4r1.1, c5r1.1, c6r1.1
row2: J1.13, J2.3, c0r2.1, c1r2.1, c2r2.1, c3r2.1, c4r2.1, c5r2.1, c6r2.1
row3: J1.12, J2.4, c0r3.1, c1r3.1, c2r3.1, c3r3.1, c4r3.1, c5r3.1, c6r3.1, c7r3.1
row4: J1.11, J2.5, c0r4.1, c1r4.1, c2r4.1, c3r4.1, c4r4.1, c5r4.1, c6r4.1, c7r4.1

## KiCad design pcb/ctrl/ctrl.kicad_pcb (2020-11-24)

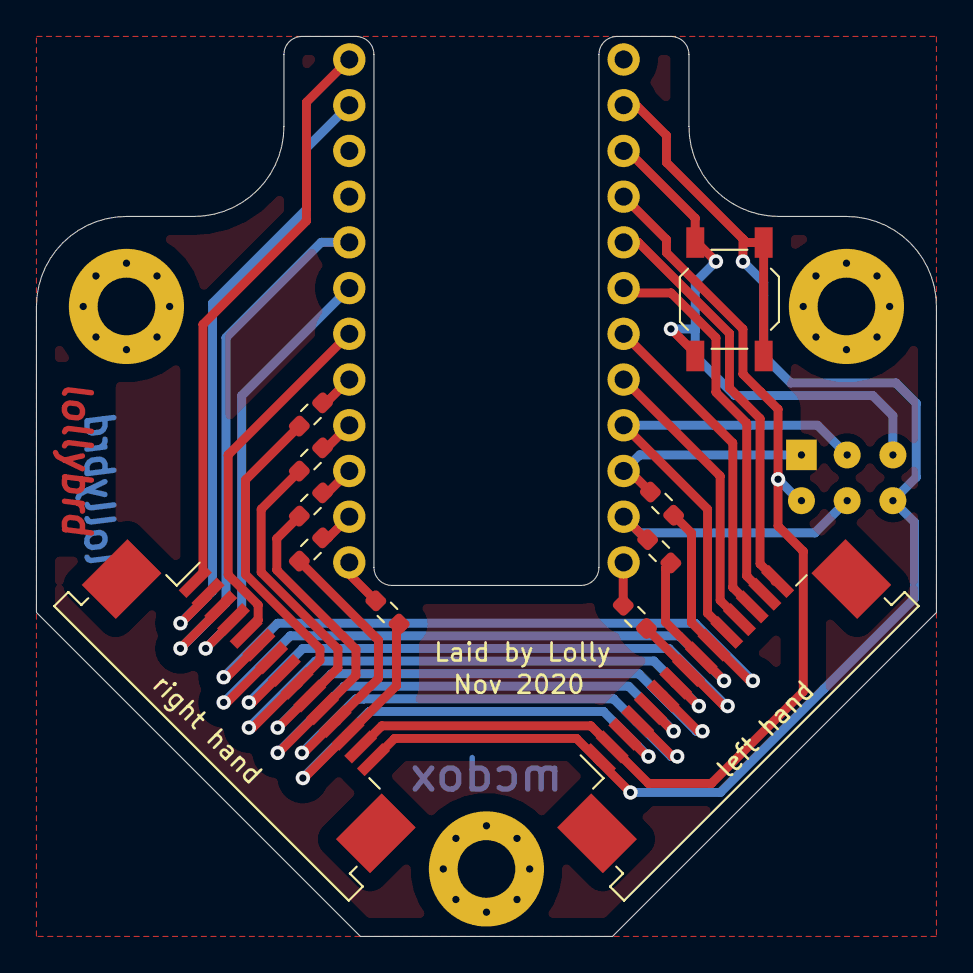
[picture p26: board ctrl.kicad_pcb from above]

Board: 2 copper layers, 50.0 x 50.0 mm, 13 parts (1 on the bottom side), 29 nets.

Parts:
ICSP: Conn_02x03_Odd_Even; PinHeader_2x03_P2.54mm_Vertical
Jleft1: Conn_01x15; TE_1-84953-5_1x15-1MP_P1.0mm_Horizontal
Jright1: Conn_01x15; TE_1-84953-5_1x15-1MP_P1.0mm_Horizontal
R0, R1, R2, R3, R4, R5, R6, R7: 220; R_0603_1608Metric_Pad0.98x0.95mm_HandSolder
SW1: SW_Push; SW_SPST_TL3342
U1: ArduinoProMicro

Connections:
GND: ICSP.6, Jleft1.1, Jright1.15, SW1.2, U1.14
MISO: ICSP.1, R0.2, U1.22
MOSI: ICSP.4, R1.2, U1.23
unnamed: R2.2, U1.24
unnamed: R3.2, U1.12
unnamed: R4.2, U1.11
unnamed: R5.2, U1.10
unnamed: R6.2, U1.9
unnamed: R7.2, U1.8
RST: ICSP.5, SW1.1, U1.15
SCK: ICSP.3, Jleft1.11, U1.21
VCC: ICSP.2, Jleft1.2, Jright1.14, U1.16
col0: Jleft1.10, Jright1.6, R0.1
col1: Jleft1.9, Jright1.7, R1.1
col2: Jleft1.8, Jright1.8, R2.1
col3: Jleft1.7, Jright1.9, R7.1
col4: Jleft1.6, Jright1.10, R6.1
col5: Jleft1.5, Jright1.11, R5.1
col6: Jleft1.4, Jright1.12, R4.1
col7: Jleft1.3, Jright1.13, R3.1
row0: Jright1.1, U1.1
row1: Jright1.2, U1.2
row2: Jright1.3, U1.5
row3: Jright1.4, U1.6
row4: Jright1.5, U1.7
row6: Jleft1.12, U1.20
row7: Jleft1.13, U1.19
row8: Jleft1.14, U1.18
row9: Jleft1.15, U1.17

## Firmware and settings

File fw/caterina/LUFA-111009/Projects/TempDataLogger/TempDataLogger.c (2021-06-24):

/*
             LUFA Library
     Copyright (C) Dean Camera, 2011.

  dean [at] fourwalledcubicle [dot] com
           www.lufa-lib.org
*/

/*
  Copyright 2011  Dean Camera (dean [at] fourwalledcubicle [dot] com)

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
  The author disclaim all warranties with regard to this
  software, including all implied warranties of merchantability
  and fitness.  In no event shall the author be liable for any
  special, indirect or consequential damages or any damages
  whatsoever resulting from loss of use, data or profits, whether
  in an action of contract, negligence or other tortious action,
  arising out of or in connection with the use or performance of
  this software.
*/

/** \file
 *
 *  Main source file for the TemperatureDataLogger project. This file contains the main tasks of
 *  the project and is responsible for the initial application hardware configuration.
 */

#include "TempDataLogger.h"

/** LUFA Mass Storage Class driver interface configuration and state information. This structure is
 *  passed to all Mass Storage Class driver functions, so that multiple instances of the same class
 *  within a device can be differentiated from one another.
 */
USB_ClassInfo_MS_Device_t Disk_MS_Interface =
	{
		.Config =
			{
				.InterfaceNumber           = 0,

				.DataINEndpointNumber      = MASS_STORAGE_IN_EPNUM,
				.DataINEndpointSize        = MASS_STORAGE_IO_EPSIZE,
				.DataINEndpointDoubleBank  = false,

				.DataOUTEndpointNumber     = MASS_STORAGE_OUT_EPNUM,
				.DataOUTEndpointSize       = MASS_STORAGE_IO_EPSIZE,
				.DataOUTEndpointDoubleBank = false,

				.TotalLUNs                 = 1,
			},
	};

/** Buffer to hold the previously generated HID report, for comparison purposes inside the HID class driver. */
static uint8_t PrevHIDReportBuffer[GENERIC_REPORT_SIZE];

/** LUFA HID Class driver interface configuration and state information. This structure is
 *  passed to all HID Class driver functions, so that multiple instances of the same class
 *  within a device can be differentiated from one another.
 */
USB_ClassInfo_HID_Device_t Generic_HID_Interface =
	{
		.Config =
			{
				.InterfaceNumber              = 1,

				.ReportINEndpointNumber       = GENERIC_IN_EPNUM,
				.ReportINEndpointSize         = GENERIC_EPSIZE,
				.ReportINEndpointDoubleBank   = false,

				.PrevReportINBuffer           = PrevHIDReportBuffer,
				.PrevReportINBufferSize       = sizeof(PrevHIDReportBuffer),
			},
	};

/** Non-volatile Logging Interval value in EEPROM, stored as a number of 500ms ticks */
static uint8_t EEMEM LoggingInterval500MS_EEPROM = DEFAULT_LOG_INTERVAL;

/** SRAM Logging Interval value fetched from EEPROM, stored as a number of 500ms ticks */
static uint8_t LoggingInterval500MS_SRAM;

/** Total number of 500ms logging ticks elapsed since the last log value was recorded */
static uint16_t CurrentLoggingTicks;

/** FAT Fs structure to hold the internal state of the FAT driver for the Dataflash contents. */
static FATFS DiskFATState;

/** FAT Fs structure to hold a FAT file handle for the log data write destination. */
static FIL TempLogFile;


/** ISR to handle the 500ms ticks for sampling and data logging */
ISR(TIMER1_COMPA_vect, ISR_BLOCK)
{
	uint8_t LEDMask = LEDs_GetLEDs();

	/* Check to see if the logging interval has expired */
	if (++CurrentLoggingTicks < LoggingInterval500MS_SRAM)
	  return;

	/* Reset log tick counter to prepare for next logging interval */
	CurrentLoggingTicks = 0;

	LEDs_SetAllLEDs(LEDMASK_USB_BUSY);

	/* Only log when not connected to a USB host */
	if (USB_DeviceState == DEVICE_STATE_Unattached)
	{
		TimeDate_t CurrentTimeDate;
		DS1307_GetTimeDate(&CurrentTimeDate);

		char     LineBuffer[100];
		uint16_t BytesWritten;

		BytesWritten = sprintf(LineBuffer, "%02d/%02d/20%02d, %02d:%02d:%02d, %d Degrees\r\n",
		                       CurrentTimeDate.Day, CurrentTimeDate.Month, CurrentTimeDate.Year,
		                       CurrentTimeDate.Hour, CurrentTimeDate.Minute, CurrentTimeDate.Second,
		                       Temperature_GetTemperature());

		f_write(&TempLogFile, LineBuffer, BytesWritten, &BytesWritten);
		f_sync(&TempLogFile);
	}

	LEDs_SetAllLEDs(LEDMask);
}

/** Main program entry point. This routine contains the overall program flow, including initial
 *  setup of all components and the main program loop.
 */
int main(void)
{
	SetupHardware();

	/* Fetch logging interval from EEPROM */
	LoggingInterval500MS_SRAM = eeprom_read_byte(&LoggingInterval500MS_EEPROM);

	/* Check if the logging interval is invalid (0xFF) indicating that the EEPROM is blank */
	if (LoggingInterval500MS_SRAM == 0xFF)
	  LoggingInterval500MS_SRAM = DEFAULT_LOG_INTERVAL;

	/* Mount and open the log file on the Dataflash FAT partition */
	OpenLogFile();

	LEDs_SetAllLEDs(LEDMASK_USB_NOTREADY);
	sei();

	for (;;)
	{
		MS_Device_USBTask(&Disk_MS_Interface);
		HID_Device_USBTask(&Generic_HID_Interface);
		USB_USBTask();
	}
}

/** Opens the log file on the Dataflash's FAT formatted partition according to the current date */
void OpenLogFile(void)
{
	char LogFileName[12];

	/* Get the current date for the filename as "DDMMYY.csv" */
	TimeDate_t CurrentTimeDate;
	DS1307_GetTimeDate(&CurrentTimeDate);
	sprintf(LogFileName, "%02d%02d%02d.csv", CurrentTimeDate.Day, CurrentTimeDate.Month, CurrentTimeDate.Year);

	/* Mount the storage device, open the file */
	f_mount(0, &DiskFATState);
	f_open(&TempLogFile, LogFileName, FA_OPEN_ALWAYS | FA_WRITE);
	f_lseek(&TempLogFile, TempLogFile.fsize);
}

/** Closes the open data log file on the Dataflash's FAT formatted partition */
void CloseLogFile(void)
{
	/* Sync any data waiting to be written, unmount the storage device */
	f_sync(&TempLogFile);
	f_close(&TempLogFile);
}

/** Configures the board hardware and chip peripherals for the demo's functionality. */
void SetupHardware(void)
{
	/* Disable watchdog if enabled by bootloader/fuses */
	MCUSR &= ~(1 << WDRF);
	wdt_disable();

	/* Disable clock division */
	clock_prescale_set(clock_div_1);

	/* Hardware Initialization */
	LEDs_Init();
	SPI_Init(SPI_SPEED_FCPU_DIV_2 | SPI_SCK_LEAD_FALLING | SPI_SAMPLE_TRAILING | SPI_MODE_MASTER);
	ADC_Init(ADC_FREE_RUNNING | ADC_PRESCALE_128);
	Temperature_Init();
	Dataflash_Init();
	USB_Init();
	TWI_Init(TWI_BIT_PRESCALE_4, TWI_BITLENGTH_FROM_FREQ(4, 50000));

	/* 500ms logging interval timer configuration */
	OCR1A   = (((F_CPU / 1024) / 2) - 1);
	TCCR1B  = (1 << WGM12) | (1 << CS12) | (1 << CS10);
	TIMSK1  = (1 << OCIE1A);

	/* Clear Dataflash sector protections, if enabled */
	DataflashManager_ResetDataflashProtections();
}

/** Event handler for the library USB Connection event. */
void EVENT_USB_Device_Connect(void)
{
	LEDs_SetAllLEDs(LEDMASK_USB_ENUMERATING);

	/* Close the log file so that the host has exclusive filesystem access */
	CloseLogFile();
}

/** Event handler for the library USB Disconnection event. */
void EVENT_USB_Device_Disconnect(void)
{
	LEDs_SetAllLEDs(LEDMASK_USB_NOTREADY);

	/* Mount and open the log file on the Dataflash FAT partition */
	OpenLogFile();
}

/** Event handler for the library USB Configuration Changed event. */
void EVENT_USB_Device_ConfigurationChanged(void)
{
	bool ConfigSuccess = true;

	ConfigSuccess &= HID_Device_ConfigureEndpoints(&Generic_HID_Interface);
	ConfigSuccess &= MS_Device_ConfigureEndpoints(&Disk_MS_Interface);

	LEDs_SetAllLEDs(ConfigSuccess ? LEDMASK_USB_READY : LEDMASK_USB_ERROR);
}

/** Event handler for the library USB Control Request reception event. */
void EVENT_USB_Device_ControlRequest(void)
{
	MS_Device_ProcessControlRequest(&Disk_MS_Interface);
	HID_Device_ProcessControlRequest(&Generic_HID_Interface);
}

/** Mass Storage class driver callback function the reception of SCSI commands from the host, which must be processed.
 *
 *  \param[in] MSInterfaceInfo  Pointer to the Mass Storage class interface configuration structure being referenced
 */
bool CALLBACK_MS_Device_SCSICommandReceived(USB_ClassInfo_MS_Device_t* const MSInterfaceInfo)
{
	bool CommandSuccess;

	LEDs_SetAllLEDs(LEDMASK_USB_BUSY);
	CommandSuccess = SCSI_DecodeSCSICommand(MSInterfaceInfo);
	LEDs_SetAllLEDs(LEDMASK_USB_READY);

	return CommandSuccess;
}

/** HID class driver callback function for the creation of HID reports to the host.
 *
 *  \param[in]     HIDInterfaceInfo  Pointer to the HID class interface configuration structure being referenced
 *  \param[in,out] ReportID    Report ID requested by the host if non-zero, otherwise callback should set to the
 *                             generated report ID
 *  \param[in]     ReportType  Type of the report to create, either HID_REPORT_ITEM_In or HID_REPORT_ITEM_Feature
 *  \param[out]    ReportData  Pointer to a buffer where the created report should be stored
 *  \param[out]    ReportSize  Number of bytes written in the report (or zero if no report is to be sent
 *
 *  \return Boolean true to force the sending of the report, false to let the library determine if it needs to be sent
 */
bool CALLBACK_HID_Device_CreateHIDReport(USB_ClassInfo_HID_Device_t* const HIDInterfaceInfo,
                                         uint8_t* const ReportID,
                                         const uint8_t ReportType,
                                         void* ReportData,
                                         uint16_t* const ReportSize)
{
	Device_Report_t* ReportParams = (Device_Report_t*)ReportData;

	DS1307_GetTimeDate(&ReportParams->TimeDate);

	ReportParams->LogInterval500MS = LoggingInterval500MS_SRAM;

	*ReportSize = sizeof(Device_Report_t);
	return true;
}

/** HID class driver callback function for the processing of HID reports from the host.
 *
 *  \param[in] HIDInterfaceInfo  Pointer to the HID class interface configuration structure being referenced
 *  \param[in] ReportID    Report ID of the received report from the host
 *  \param[in] ReportType  The type of report that the host has sent, either HID_REPORT_ITEM_Out or HID_REPORT_ITEM_Feature
 *  \param[in] ReportData  Pointer to a buffer where the received report has been stored
 *  \param[in] ReportSize  Size in bytes of the received HID report
 */
void CALLBACK_HID_Device_ProcessHIDReport(USB_ClassInfo_HID_Device_t* const HIDInterfaceInfo,
                                          const uint8_t ReportID,
                                          const uint8_t ReportType,
                                          const void* ReportData,
                                          const uint16_t ReportSize)
{
	Device_Report_t* ReportParams = (Device_Report_t*)ReportData;
	
	DS1307_SetTimeDate(&ReportParams->TimeDate);

	/* If the logging interval has changed from its current value, write it to EEPROM */
	if (LoggingInterval500MS_SRAM != ReportParams->LogInterval500MS)
	{
		LoggingInterval500MS_SRAM = ReportParams->LogInterval500MS;
		eeprom_update_byte(&LoggingInterval500MS_EEPROM, LoggingInterval500MS_SRAM);
	}
}

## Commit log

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2014-11-05 Initial add of PCB project with only test PCB to prove out the footprints and routing method.
    [mcdox.kicad_pcb, mcdox.sch]
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2014-11-16 Generate per layer DXFs to for laser cutters.
    [dim_test.dxf, mcdox_all.dxf, mcdox_base0_2mm.dxf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]
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2014-11-19 Add missed header footprint copied from std repo.
2014-11-22 Initial fully routed layout.
    Entirely done with DRC turned off as the alpsmx footprint doesn't comply.
    Therefore I'll really need to get one made to test if it all works.
    All the footprints were placed using the mcdox_kicad.py script.
    [mcdox-hand0.kicad_pcb]
2014-11-22 Modify base layers to make space for final PCB outline.
    Since the PCB is cut with a 0.8mm mill, and the base layers with a ~0.3mm
    laser, there should be ~0.55mm clearance all round.
    [mcdox_all.dxf, mcdox_base1_4mm.dxf, mcdox_base2_4mm.dxf]
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2014-11-27 Footprint updates to make routing easier with thicker tracks.
    Correct diode direction marked with square pads.
    Add diode symbols to silkscreen.
    Increased foootprint track width to 0.5mm to make DIY etching easier.
2014-12-01 Footprint update after getting first run of test boards.
    Increased length of all rect smd pads to make solderign easier.
    Moved reference and name to corner for better printing.
    Joining pads on B.Cu now have solder mask on correct side.
    LED square cutout now drawn at full size for fill milling since that's
    what Seeed seem to do. As opposed to follow milling.
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2014-12-04 Move reference/value in footprint to make silkscreen nicer.
    [mcdox.kicad_pcb]
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2014-12-04 Give 0.5mm margic round PCB to account for edge cuts changing size in PCB.
    The holes under switches were done with a fill-in rather than follow so
    I'm assuming the edge will be the same.
    [mcdox_all.dxf, mcdox_base1_4mm.dxf, mcdox_base2_4mm.dxf]
2014-12-07 Corrected pinout on schematic to match PCB.
    [mcdox.sch]
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2014-12-16 Initial add of keycap SCAD model.
    Refactored and modified from http://www.thingiverse.com/thing:468651
    Still to add stems for Matias/ALPS.
    [keycap.scad]
2014-12-16 Added ALPS stem support and some minor tidy.
    [keycap.scad]
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2014-12-16 Add simple script to generate STLs for all the combinations.
    Primarily to make downloading from github easier.
    Not finished yet as I need to get to bed.
    [keycap.scad]
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2014-12-19 Fix script to render all the different configuratons of keycap STL files.
2014-12-19 Assorted keycap scad updates.
    Added supports for very high caps.
    Some refactoring to tidy.
    [keycap.scad]
2014-12-19 Put line type to unix. Not sure how it managed to get bad.
    [keycap.scad]
2014-12-19 Last minute fixes.
    [keycap.scad]
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2014-12-19 Add 3mm and 5mm generation to case DXFs.
    [mcdox_base0_3mm.dxf, mcdox_base1_3mm.dxf, mcdox_base2_5mm.dxf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]
2014-12-19 Generate Matias/ALPS case by default as that's the first one I'll do.
    [mcdox_all.dxf, mcdox_base0_2mm.dxf, mcdox_base0_3mm.dxf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]
2014-12-22 Add DXF generator for laser cut keycaps for Matias switches.
    [alps_caps_3mm.dxf, alps_stems_2mm.dxf]
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2014-12-26 Updates for ALPS laser cut caps.
    Added DXF for jig and packing cardboard.
    Modified measurements to compensate for laser kerf.
    [alps_caps_3mm.dxf, alps_cardpack_6mm.dxf, alps_jig_cnc.dxf]
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2014-12-26 Label fixes.
    [#alps_caps_mcdoxright_3mm.dxf, alps_caps_mcdoxleft_3mm.dxf]
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2014-12-29 Make PCB spacer 10mm.
    They don't *have* to be 10mm diameter but it makes the PCB mounting holes
    nicely inset and is an easy to remember size.
    [mcdox_all.dxf, mcdox_mnt_2mm.dxf, mcdox_mnt_3mm.dxf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]
2014-12-29 Updated Lolly's first board which is now sent off to Seeed Studio for production.
    [ctrl_teensy.kicad_pcb]
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2014-12-30 Corrected pcb profiling in base cutouts.
    [mcdox_all.dxf, mcdox_base1_3mm.dxf, mcdox_base1_4mm.dxf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]
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2014-12-30 Add option to cut caps from the same piece of plastic as the top layer.
    This saves on material but only works if a 2 or 3mm top layer is used.
    [mcdox_all.dxf, mcdox_top2_2mm.dxf]
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2014-12-31 Added profile space for keycaps on top layers.
    [mcdox_all.dxf, mcdox_top0_4mm.dxf, mcdox_top0_5mm.dxf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]
2015-01-04 Make room for IDC connector on PCB in base layers of case.
    [mcdox_all.dxf, mcdox_base0_2mm.dxf, mcdox_base0_3mm.dxf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]
2015-01-24 Massive changes to shape.
    Realised that the two-circles shape won't fit on a 600x400 sheet so needed
    to trim it down a bit.
    While doing that a neater way specifying the paths is used which makes it
    easier to read.
    Changed default thicknesses to 3 and 5 since they are the standard.
    [mcdox_all.dxf, mcdox_base0_3mm.dxf, mcdox_base1_3mm.dxf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]
2015-01-24 More lined up with origin but still not quite. Good enough for now.
    [mcdox_all.dxf, mcdox_base0_3mm.dxf, mcdox_base1_5mm.dxf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]
2015-01-26 Update keycap dimensions after 1st sneaky proto run.
    [alps_caps_3mm.dxf, alps_caps_mcdoxleft_3mm.dxf, alps_caps_mcdoxright_3mm.dxf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]
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2015-01-29 Slight re-ordering of cap blocks since adding SVG support.
    Visually and functionally the same.
    [mcdox_all.dxf, mcdox_top2_3mm.dxf]
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2015-01-30 Add laid out cuts for 600x400mm from Hindleys.
    [mcdox_3mm_alps.dxf, mcdox_3mm_cherrymx.dxf, mcdox_5mm.dxf]
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2015-02-07 Name change to give version precedence over box size.
    [alps_caps_3mm_x2.dxf, alps_cardpack_6mm_x1.dxf, alps_stems_2mm_x1.dxf]
2015-02-07 Receiver hole changes for v0.2
    v0.1 receiver holes were just a tad too thin for the stems to fit in.
    [alps_caps_3mm_x1[no_protective_film].dxf, alps_cardpack_6mm_x1.dxf, alps_jig_cnc.dxf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]
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2015-02-11 Initial add of ambrd.
    For now it's only a clone of a Teensy2.0 with a programming header.
    Still to add LED drivers (maybe MAX7313?) and wire up IDC connectors.
    [ambrd.sch]
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2015-02-19 Add dimensions test for stem holes as these seem to be problematic.
    [alps_dimtest_3mm.dxf]
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2015-03-09 Move values on MAX7313 to look like the uC.
    [ambrd.sch]
2015-03-12 Split 26 pin 2x13 into separate 1x13 header rows to make changing orientation easier.
    [ambrd.sch]
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2015-03-19 Enlarge stem recv hole by 0.1mm to account for bad tolerences in 2mm acrylic. Also make the stem 0.1mm smaller for easier for in switch.
    [mcdox_all.dxf, mcdox_top2_3mm.dxf]
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2015-06-30 Remove dodgy derived files, generate both alps and cherrymx mnt plates.
    [alps_stems_2mm.dxf, mcdox_3mm_alps.dxf, mcdox_3mm_cherrymx.dxf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]
2015-07-05 Fix hole diameter needs to be just a little bigger to allow screws to insert easily.
2015-07-05 Remove DXF generation for case.
    SVG is now the only supported format for generating the case.
    Postprocessing can be done in Inkscape if other formats are needed.
    [dim_test.dxf, mcdox_all.dxf, mcdox_base0_3mm.dxf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]
2015-07-05 Fix holes 2.9 to 3.3mm.
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2016-06-06 Slightly move fixing holes to work nicer with smallthumb.
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2016-06-12 Revert "Add misc_holes for securing battery cells."
    This reverts commit 31d76a2599f51ea8be9e0675ba8927fad5602f19.
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2016-06-12 Remove old-name layerstack diagram.
    New layers are actually 1.5mm for Cherry switches to grip.
    Missed due to filesystem weirdness.
2016-06-12 Remove the very close fixing holes at bottom center.
    These require 2 extra bolts but don't seem to provide much support.
    They are most useful for keeping headphone cable under the board in the
    middle but that just encourages my OCD.
    The headphones actually have less freedom of movement there.
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2016-06-12 Thicken the profile for midmnt to prevent 1.5mm acrylic snapping on switch insertion.
2016-06-12 Simplify name/code for fixing hole radius.
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2020-11-14 rm keycap DXF generator for ALPS.
    These keycaps are okay for a single switch, but totally naff for a whole keyboard.
    [alps_caps_3mm.dxf, alps_caps_3mm_x1[no_protective_film].dxf, alps_caps_3mm_x2.dxf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]
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2020-11-15 pcb/hand Partial workaround for issue with copper graphics in footprint. WIP
    [hand.kicad_pcb]
2020-11-15 pcb/hand 0603 diode and pad-hack on 1.5x footprints.
    [hand.kicad_pcb]
2020-11-15 hand/pcb Routing complete and proper NPTH holes without mask.
    [hand.kicad_pcb, hand.sch]
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2020-11-18 case/layerstack All 3mm with sketches for cutouts.
    Avoid big flappy sections like on 1.0.
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2020-11-19 pcb/hand Thumb cluster rewired but not connected to rest of hand.
    checkpoint
    [hand.kicad_pcb]
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2020-11-19 pcb/hand Vanity features on one side only to save space.
    Max dimensions 174x125.5mm
    [hand.kicad_pcb]
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2020-11-28 layerstack Correct height of FFC connectors
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2020-12-03 case Move asymmetric hole non-blocking mistake.
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2020-12-03 case Release fixes after today's lasercut session.
    [cut.coverBottom.dxf, cut.coverTop.dxf, cut.innerBottom0.dxf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]
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2021-01-05 keycap Replace octuple with isogrid.
    [isogrid.scad, octuple.scad]
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2021-01-06 keycap mv gatePair.margin gatePair.overshoot
    [isogrid.scad]
2021-01-06 keycap rm mentions of FDM brim because FDM doesn't meet acceptable tolerances.
    [keycap.scad, keycapStem.scad]
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2021-01-06 keycap Vent location, missing primary channel.
    [keycap.scad, moldIsogrid.scad]
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2021-02-16 case Enlarge innerTop cutouts to prevent keycap jamming.
    [cut.innerTop.dxf]
2021-06-24 Bootloader for Sparkfun Pro Micro.
    If bootloader is broken I have a usbtiny programmer from Xinda to flash
    directly after building "Caterina" bootloader from source (with Sparkfun's modifcations).
    blinkHelloWorld.hex should be removed in future.
    [ConfiguringApps.txt]
